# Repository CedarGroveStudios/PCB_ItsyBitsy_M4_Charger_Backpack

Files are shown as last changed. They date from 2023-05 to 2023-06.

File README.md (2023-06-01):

### _A stacking breadboard adapter for the ItsyBitsy M4 Express_

# ItsyBitsy M4 Charger Backpack

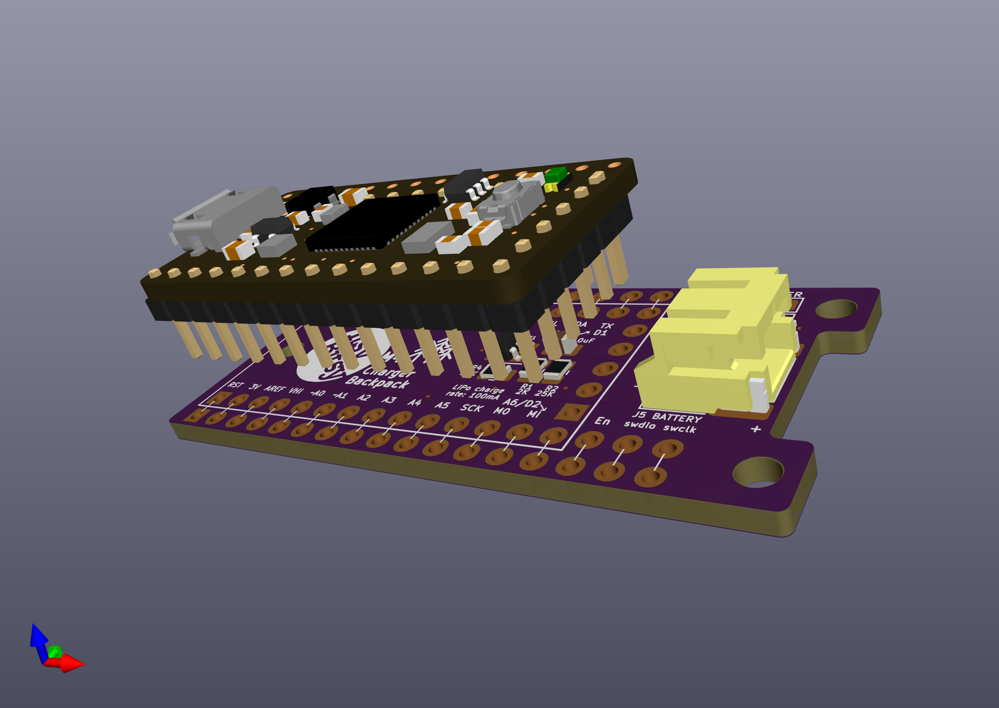
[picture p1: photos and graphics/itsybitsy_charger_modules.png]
Image of Module


## Overview
The ItsyBitsy M4 Charger Backpack is an Adafruit ItsyBitsy M4 Express-compatible piggyback module that converts the 3-sided pinout of the ItsyBitsy to dual in-line for use on typical solderless breadboards and soldered protoboards. The adapter was also designed with extra solderable pin connections.

Included is a STEMMA-QT connector that can be optionally configured via solder jumpers to connect to the ItsyBitsy's UART (RX/TX) or I2C (SCL/SDA) signals. A 2-pin JST LiPo battery connection is on-board that supports charging (100mA charge rate), compatible with Adafruit's standard battery connector polarity. A solder jumper is also provided to optionally connect the battery monitor voltage divider to pin A6.

ItsyBitsy Breadboard Adapter [Schematic](https://github.com/CedarGroveStudios/PCB_ItsyBitsy_M4_Charger_Backpack/blob/main//PCB/ItsyBitsy%20breadboard.pdf)

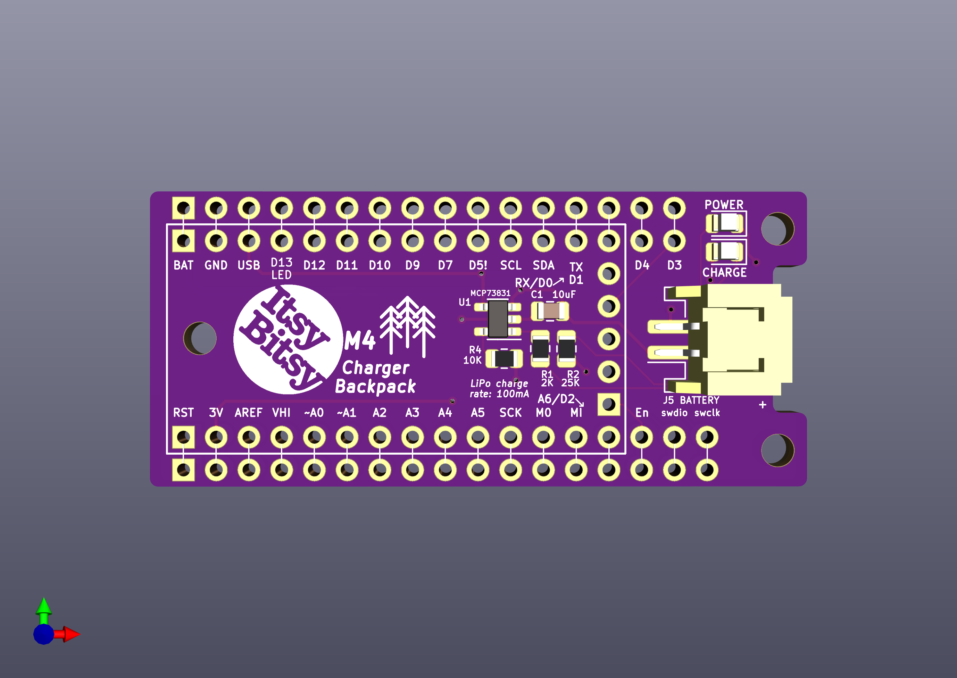
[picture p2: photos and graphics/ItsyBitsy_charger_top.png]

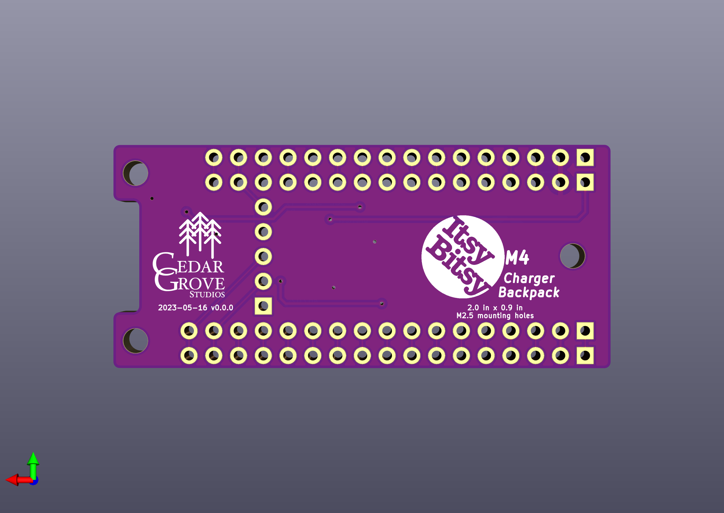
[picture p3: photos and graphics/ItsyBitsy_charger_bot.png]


OSH Park shared project:

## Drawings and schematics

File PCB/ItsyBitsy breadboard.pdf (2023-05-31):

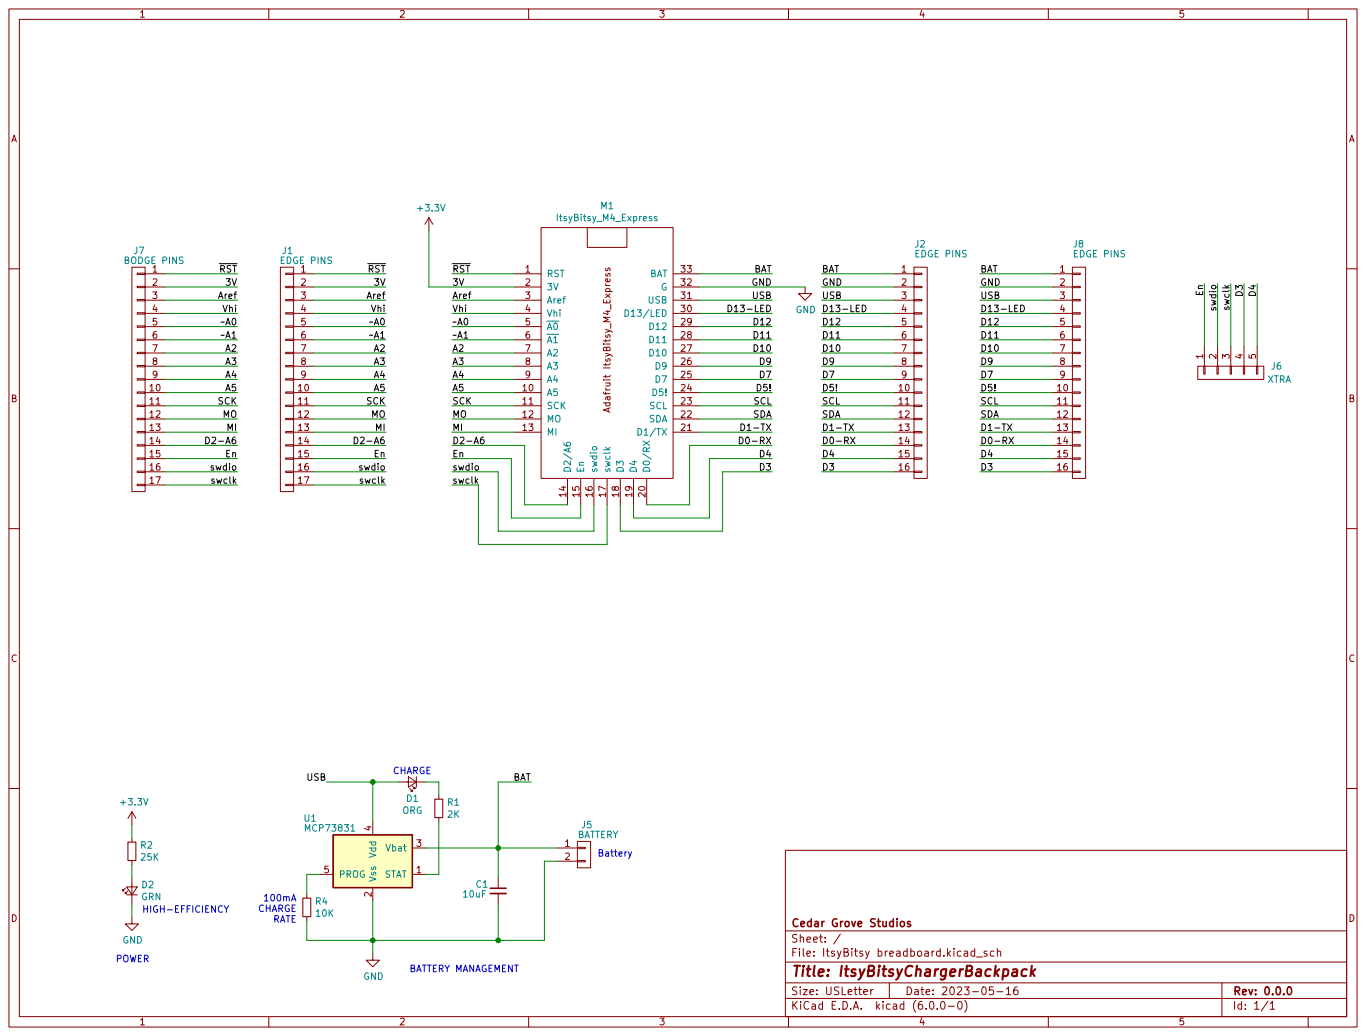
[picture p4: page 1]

J7 BODGE PINS
swdioEn D2-A6 Vhi ~A1 ~A0 ~{RST} Aref 3V

100mA CHARGE RATE HIGH-EFFICIENCY

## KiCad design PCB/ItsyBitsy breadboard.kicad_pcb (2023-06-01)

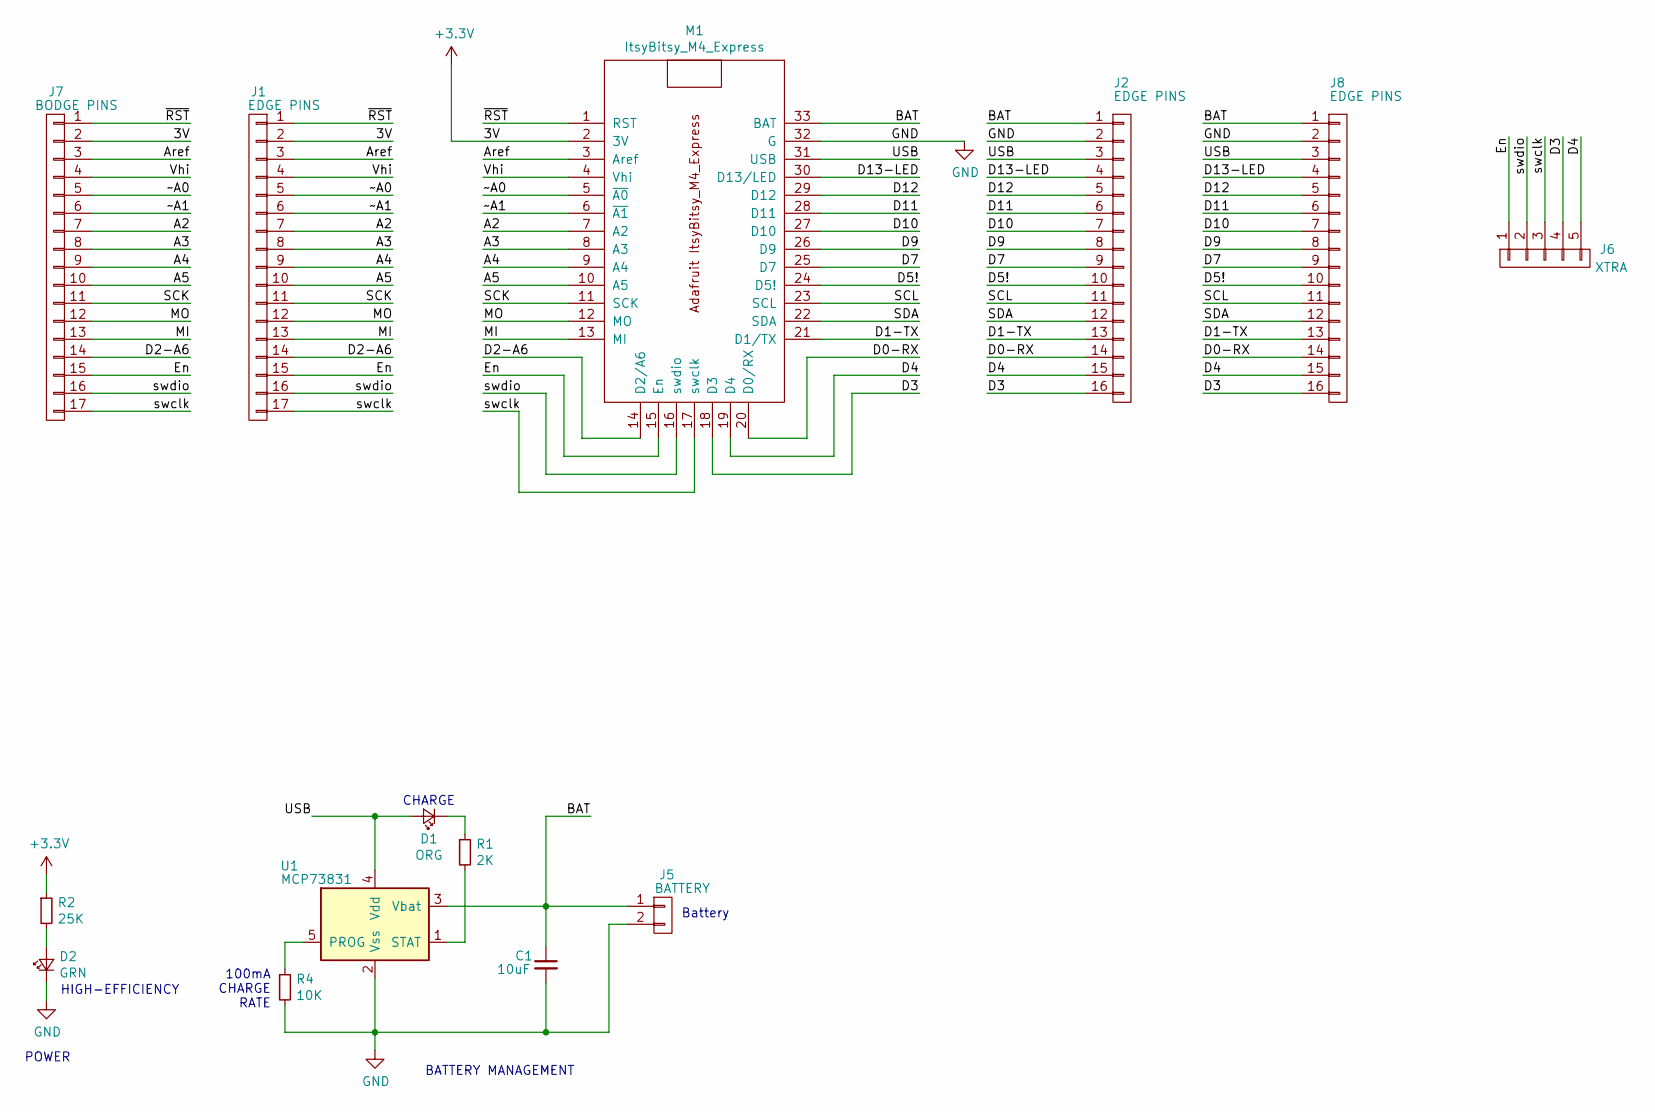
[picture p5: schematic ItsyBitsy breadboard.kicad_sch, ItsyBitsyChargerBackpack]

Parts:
C1: 10uF; C_0805_2012Metric
D1: ORG; LED_0805_2012Metric
D2: GRN; LED_0805_2012Metric
J1: EDGE PINS; Pin_Header_Straight_1x17_Pitch2.54mm_no_silk
J2, J8: EDGE PINS; Pin_Header_Straight_1x16_Pitch2.54mm_no_silk
J5: BATTERY; JST_PH_S2B-PH-SM4-TB_1x02-1MP_P2.00mm_Horizontal
J6: XTRA; Pin_Header_Straight_1x05_Pitch2.54mm_no_silk
J7: BODGE PINS; Pin_Header_Straight_1x17_Pitch2.54mm_no_silk
M1: ItsyBitsy_M4_Express
R1: 2K; R_0805_2012Metric
R2: 25K; R_0805_2012Metric
R4: 10K; R_0805_2012Metric
U1: MCP73831; SOT-23-5

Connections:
+3V3: J1.2, J7.2, M1.2 (3V), R2.1
/A2: J1.7, J7.7, M1.7 (A2)
/A3: J1.8, J7.8, M1.8 (A3)
/A4: J1.9, J7.9, M1.9 (A4)
/A5: J1.10, J7.10, M1.10 (A5)
/Aref: J1.3, J7.3, M1.3 (Aref)
/BAT: C1.1, J2.1, J5.1, J8.1, M1.33 (BAT), U1.3 (Vbat)
/D0-RX: J2.14, J8.14, M1.20 (D0/RX)
/D1-TX: J2.13, J8.13, M1.21 (D1/TX)
/D2-A6: J1.14, J7.14, M1.14 (D2/A6)
/D3: J2.16, J6.4, J8.16, M1.18 (D3)
/D4: J2.15, J6.5, J8.15, M1.19 (D4)
/D5!: J2.10, J8.10, M1.24 (D5!)
/D7: J2.9, J8.9, M1.25 (D7)
/D9: J2.8, J8.8, M1.26 (D9)
/D10: J2.7, J8.7, M1.27 (D10)
/D11: J2.6, J8.6, M1.28 (D11)
/D12: J2.5, J8.5, M1.29 (D12)
/D13-LED: J2.4, J8.4, M1.30 (D13/LED)
/En: J1.15, J6.1, J7.15, M1.15 (En)
/MI: J1.13, J7.13, M1.13 (MI)
/MO: J1.12, J7.12, M1.12 (MO)
/SCK: J1.11, J7.11, M1.11 (SCK)
/SCL: J2.11, J8.11, M1.23 (SCL)
/SDA: J2.12, J8.12, M1.22 (SDA)
/USB: D1.2 (A), J2.3, J8.3, M1.31 (USB), U1.4 (Vdd)
/Vhi: J1.4, J7.4, M1.4 (Vhi)
/swclk: J1.17, J6.3, J7.17, M1.17 (swclk)
/swdio: J1.16, J6.2, J7.16, M1.16 (swdio)
/~A0: J1.5, J7.5, M1.5 (~A0)
/~A1: J1.6, J7.6, M1.6 (~A1)
/~RST: J1.1, J7.1, M1.1 (RST)
GND: C1.2, D2.1 (K), J2.2, J5.2, J8.2, M1.32 (G), R4.2, U1.2 (Vss)
unnamed: D1.1 (K), R1.1
unnamed: D2.2 (A), R2.2
unnamed: R1.2, U1.1 (STAT)
unnamed: R4.1, U1.5 (PROG)

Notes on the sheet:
BATTERY MANAGEMENT
CHARGE
Battery
HIGH-EFFICIENCY
POWER
100mA CHARGE RATE

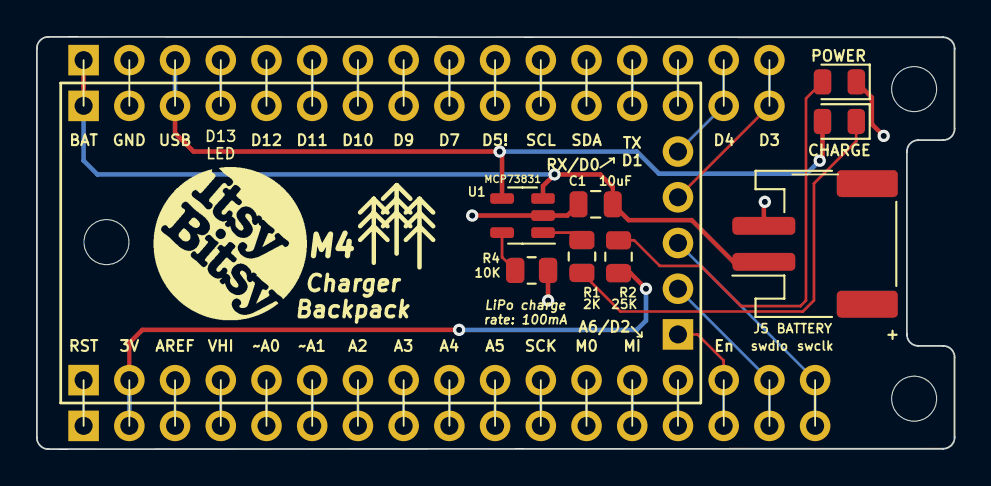
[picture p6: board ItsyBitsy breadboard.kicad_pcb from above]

Board: 2 copper layers, 51.0 x 22.9 mm, 15 parts (1 on the bottom side), 37 nets.

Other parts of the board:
logo: ItsyBitsy_logo
logo#2: ItsyBitsy_logo

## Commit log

2023-05-31 intial repo load
    [ItsyBitsy breadboard-B_Cu.gbl, ItsyBitsy breadboard-B_Mask.gbs, ItsyBitsy breadboard-B_Paste.gbp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]
2023-06-01 initial repo load
    [ItsyBitsy breadboard.kicad_pcb]
2023-06-02 update kicad backup
